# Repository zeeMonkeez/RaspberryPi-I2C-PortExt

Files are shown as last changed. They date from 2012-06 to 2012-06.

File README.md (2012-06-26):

RaspberryPi-I2C-PortExt
=======================

This is a 5V I2C 8bit port extender for RaspberryPi using an MCP23008.
Use this to connect up to 8 digital lines as inputs or outputs, with a programmable interrupt line to notify RaspberryPi of changes.
All at the 5V level.

Using an appropriate header/socket (e.g. SAMTEC ESQ-113-24-T-D, Farnell 1930727) the module is stackable.
Pinheader X3 can be fitted to select the address of the MCP with jumpers. If not fitted, wire jumpers have to be soldered in.
X4 can be soldered in so the /RST and INT lines can be connected to GPIO lines.
The I2C lines and /RST are protected by MOSFETs (according to NXP's application note). INT is level shifted using a 74LVC1G07DCK buffer. The buffer's output again is protected through R6 against accidentally setting the GPIO it's connected to as an output.
If /RST is not needed, T3 and R4 do not have to be fitted. If INT is not needed, IC2 and R6 can be left out.
For C1/C4 and C2/C3, SMD or through hole components can be used.

License
-------
<br />This work is licensed under a <a rel="license" href="http://creativecommons.org/licenses/by-sa/2.0/uk/">Creative Commons Attribution-ShareAlike 2.0 UK: England &amp; Wales License</a>.

<a target="_blank" href="http://freedomdefined.org/OSHW">OSHW</a>

&copy;2012 Jonas Zimmermann.

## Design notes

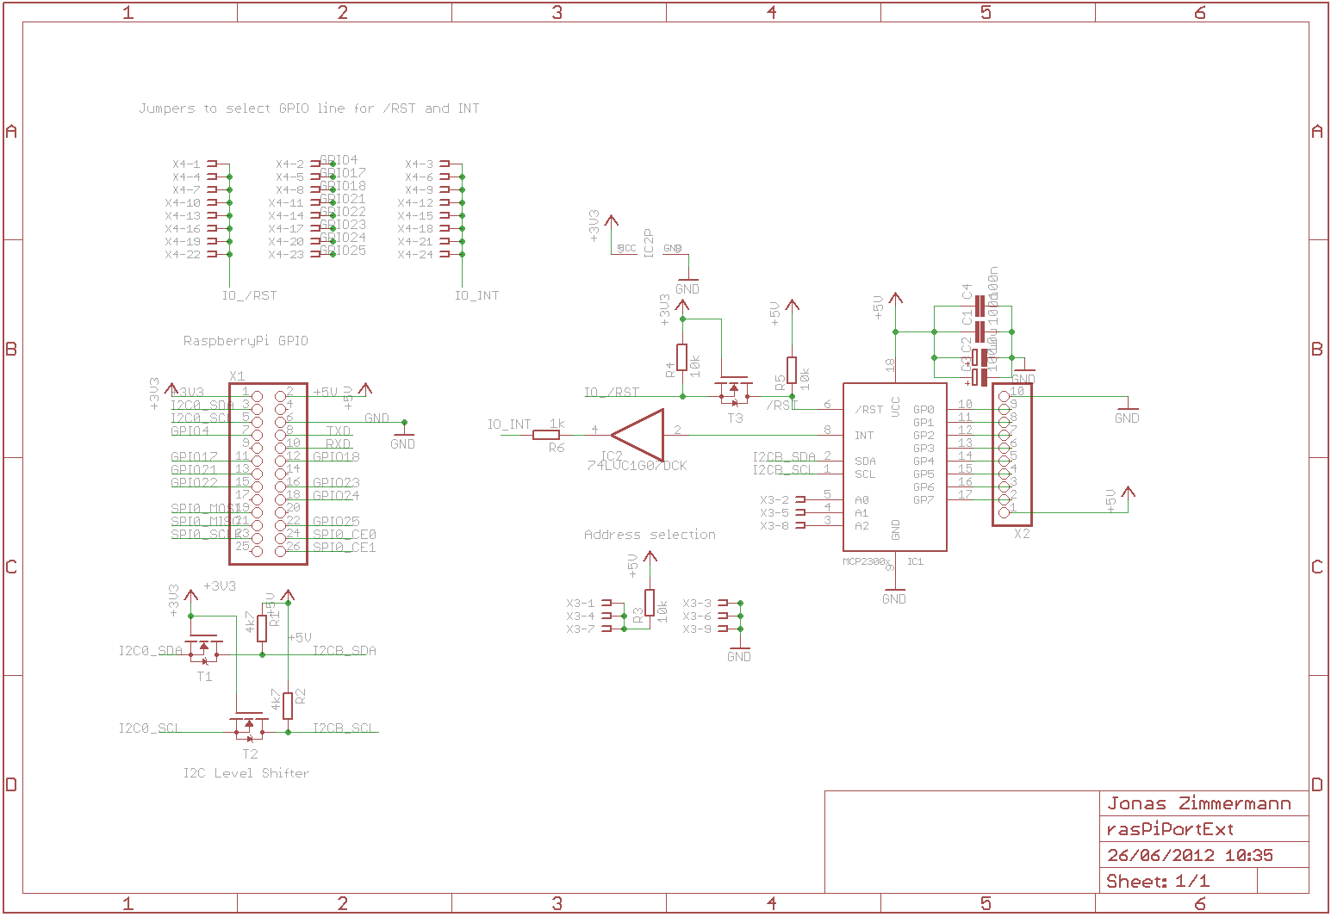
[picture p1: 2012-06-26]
rasPiPortExt-Schematic.png

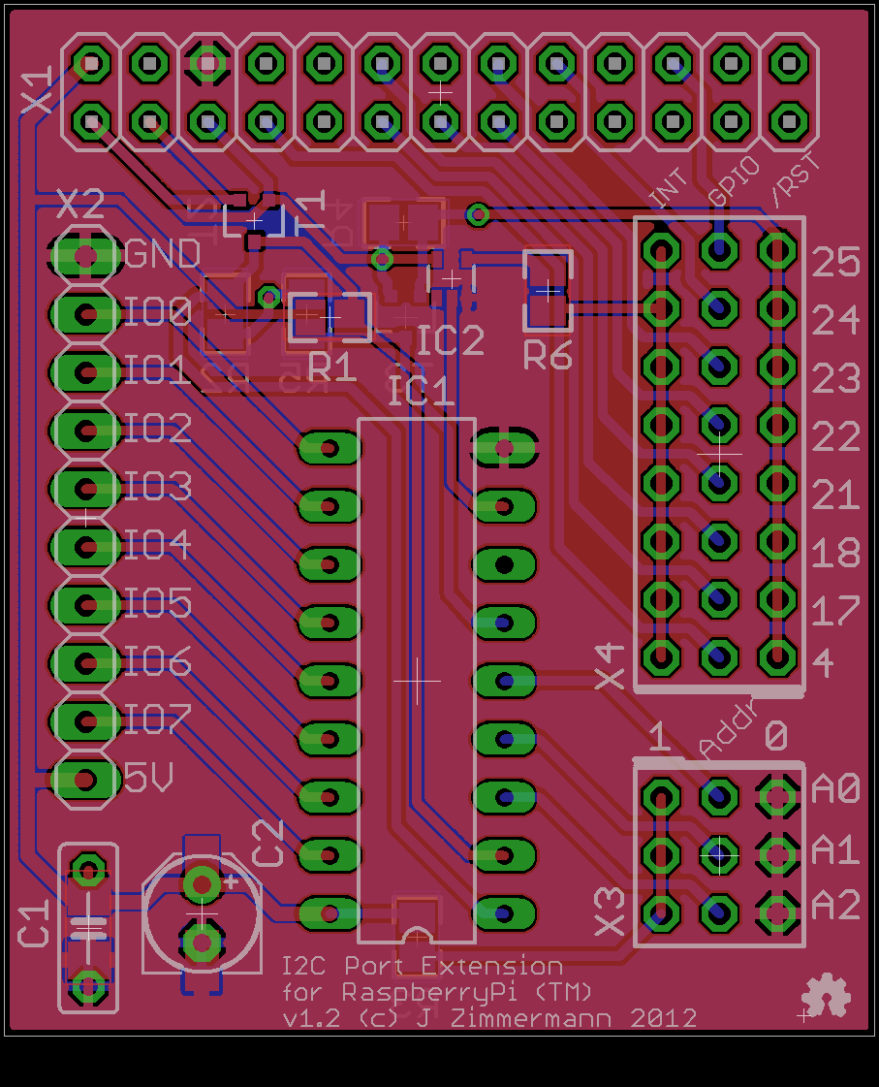
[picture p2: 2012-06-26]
rasPiPortExt-Board.png

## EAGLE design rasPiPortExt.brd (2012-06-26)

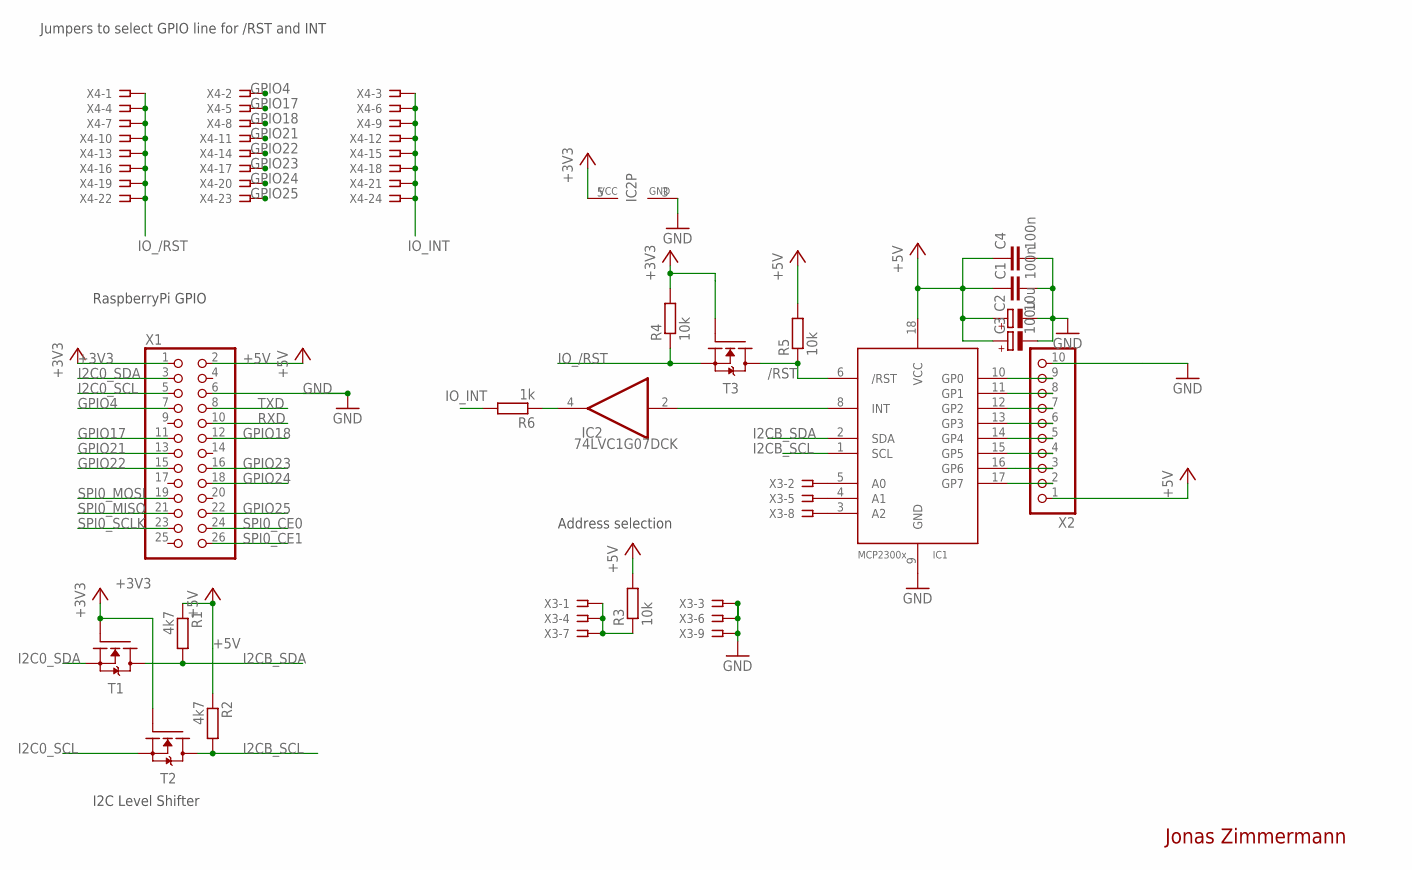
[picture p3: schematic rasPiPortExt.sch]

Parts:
C1: 100n; C1206
C2: 10u; PANASONIC_C
C3: 100u; E2,5-5
C4: 100n; C050-025X075
IC1: MCP2300X/P; DIL18
IC2: 74LVC1G07DCK; SC70-5
R1, R2: 4k7; R0805
R3, R4, R5: 10k; R0805
R6: 1k; R0805
T1, T2, T3: BSS138PW"; SOT-323
X1: PINHD-2X13; 2X13
X2: PINHD-1X10; 1X10
X3: SSW-103-02-S-T
X4: SSW-108-02-S-T

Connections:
+3V3: IC2.5 (VCC), R4.2, T1.P$1 (G), T2.P$1 (G), T3.P$1 (G), X1.1
+5V: C1.1, C2.+, C3.+, C4.1, IC1.18 (VCC), R1.1, R2.1, R3.2, R5.2, X1.2, X2.1
/RST: IC1.6 (/RST), R5.1, T3.P$3 (D)
GND: C1.2, C2.-, C3.-, C4.2, IC1.9 (GND), IC2.3 (GND), X1.6, X2.10, X3.3, X3.6, X3.9
GPIO4: X1.7, X4.2
GPIO17: X1.11, X4.5
GPIO18: X1.12, X4.8
GPIO21: X1.13, X4.11
GPIO22: X1.15, X4.14
GPIO23: X1.16, X4.17
GPIO24: X1.18, X4.20
GPIO25: X1.22, X4.23
I2C0_SCL: T2.P$2 (S), X1.5
I2C0_SDA: T1.P$2 (S), X1.3
I2CB_SCL: IC1.1 (SCL), R2.2, T2.P$3 (D)
I2CB_SDA: IC1.2 (SDA), R1.2, T1.P$3 (D)
INT: IC1.8 (INT), IC2.2 (I)
IO_/RST: R4.1, T3.P$2 (S), X4.1, X4.4, X4.7, X4.10, X4.13, X4.16, X4.19, X4.22
IO_INT: R6.2, X4.3, X4.6, X4.9, X4.12, X4.15, X4.18, X4.21, X4.24
unnamed: IC1.5 (A0), X3.2
unnamed: IC1.4 (A1), X3.5
unnamed: IC1.3 (A2), X3.8
unnamed: IC1.10 (GP0), X2.9
unnamed: IC1.11 (GP1), X2.8
unnamed: IC1.12 (GP2), X2.7
unnamed: IC1.13 (GP3), X2.6
unnamed: R3.1, X3.1, X3.4, X3.7
unnamed: IC1.14 (GP4), X2.5
unnamed: IC1.15 (GP5), X2.4
unnamed: IC1.16 (GP6), X2.3
unnamed: IC1.17 (GP7), X2.2
unnamed: IC2.4 (O), R6.1
RXD: X1.10
SPI0_CE0: X1.24
SPI0_CE1: X1.26
SPI0_MISO: X1.21
SPI0_MOSI: X1.19
SPI0_SCLK: X1.23
TXD: X1.8

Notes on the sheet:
Jumpers to select GPIO line for /RST and INT
Address selection
RaspberryPi GPIO
I2C Level Shifter
Jonas Zimmermann

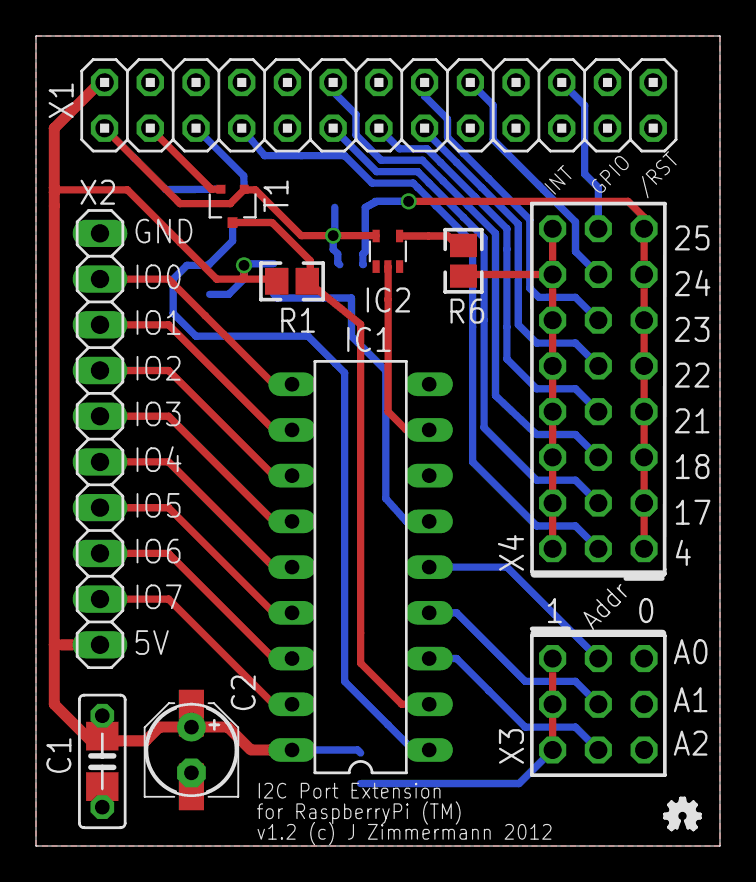
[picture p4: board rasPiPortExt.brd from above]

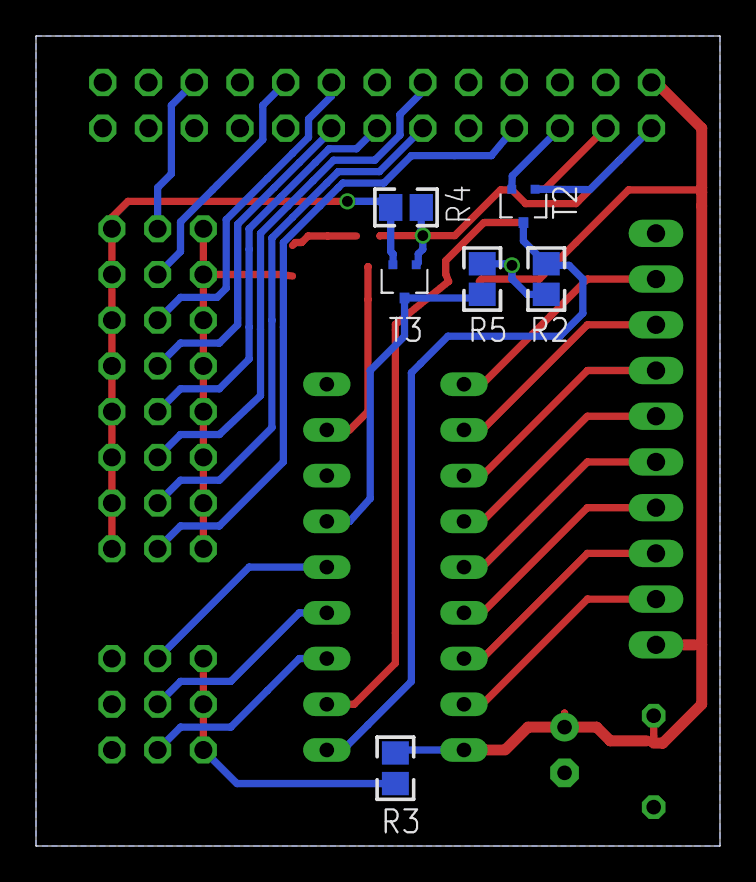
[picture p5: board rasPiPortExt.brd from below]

Board: 2 copper layers, 38.0 x 45.0 mm, 20 parts (6 on the bottom side), 32 nets.

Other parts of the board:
U$1: OSHW_FILLX70_NOTEXT

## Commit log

2012-06-24 version 1
    [rasPiPortExt.brd, rasPiPortExt.sch]
2012-06-24 changed design for /RST line, added additional R rearranged some components and traces v1.1 submitted for etching
    [rasPiPortExt.brd, rasPiPortExt.sch]
2012-06-25 improved buffer for IRQ line, adding protection resistor
    [rasPiPortExt.brd, rasPiPortExt.sch]
2012-06-25 added open source hardware logo
    [rasPiPortExt.brd]
2012-06-26 Moved a few components around, added README
    [rasPiPortExt.brd, rasPiPortExt.sch]
2012-06-26 Added PNGs for board and schematics
2012-06-26 Added comment 5V level
